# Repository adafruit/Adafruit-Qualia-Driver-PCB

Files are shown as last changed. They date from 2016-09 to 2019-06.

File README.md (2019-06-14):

## Adafruit Qualia Driver PCB

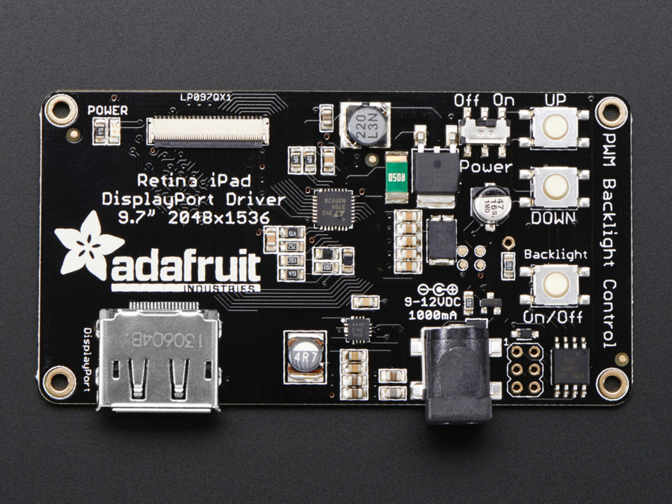
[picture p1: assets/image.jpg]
<a href="http://www.adafruit.com/products/1716"><br/>
Click here to purchase one from the Adafruit shop</a>

PCB files for the Adafruit Qualia Driver. Format is EagleCAD schematic and board layout
* https://www.adafruit.com/product/1716

### DESCRIPTION
The Qualia Retina driver board is a work of art (it was designed by resident engineer KTOWN). It's used in the Adafruit Qualia 9.7" DisplayPort Monitor Kit and we use the really awesome LT3754 as a 12-channel constant current driver with individual backlight string channel control. This gives the backlight perfect consistency over any usage or temperature range. A ATtiny85 handles the backlight dimming and soft on/off, so you can PWM the backlight over a range to get the look you want.

This driver is available for advanced users only! The Molex connector that is used to connect to the LG display is insanely delicate and breaks very very very easily if you are not very careful! If you order this driver board and break the connector, it may no longer work and we cannot repair it. If you break it you may have to buy another driver. We do not offer any returns, refunds or replacements! Do not purchase if you are not comfortable with this risk!

### License

Adafruit invests time and resources providing this open source design, please support Adafruit and open-source hardware by purchasing products from [Adafruit.com](https://www.adafruit.com)!

Designed by Adafruit Industries. 

Creative Commons Attribution, Share-Alike license, check license.txt for more information All text above must be included in any redistribution - see license.txt for more information.

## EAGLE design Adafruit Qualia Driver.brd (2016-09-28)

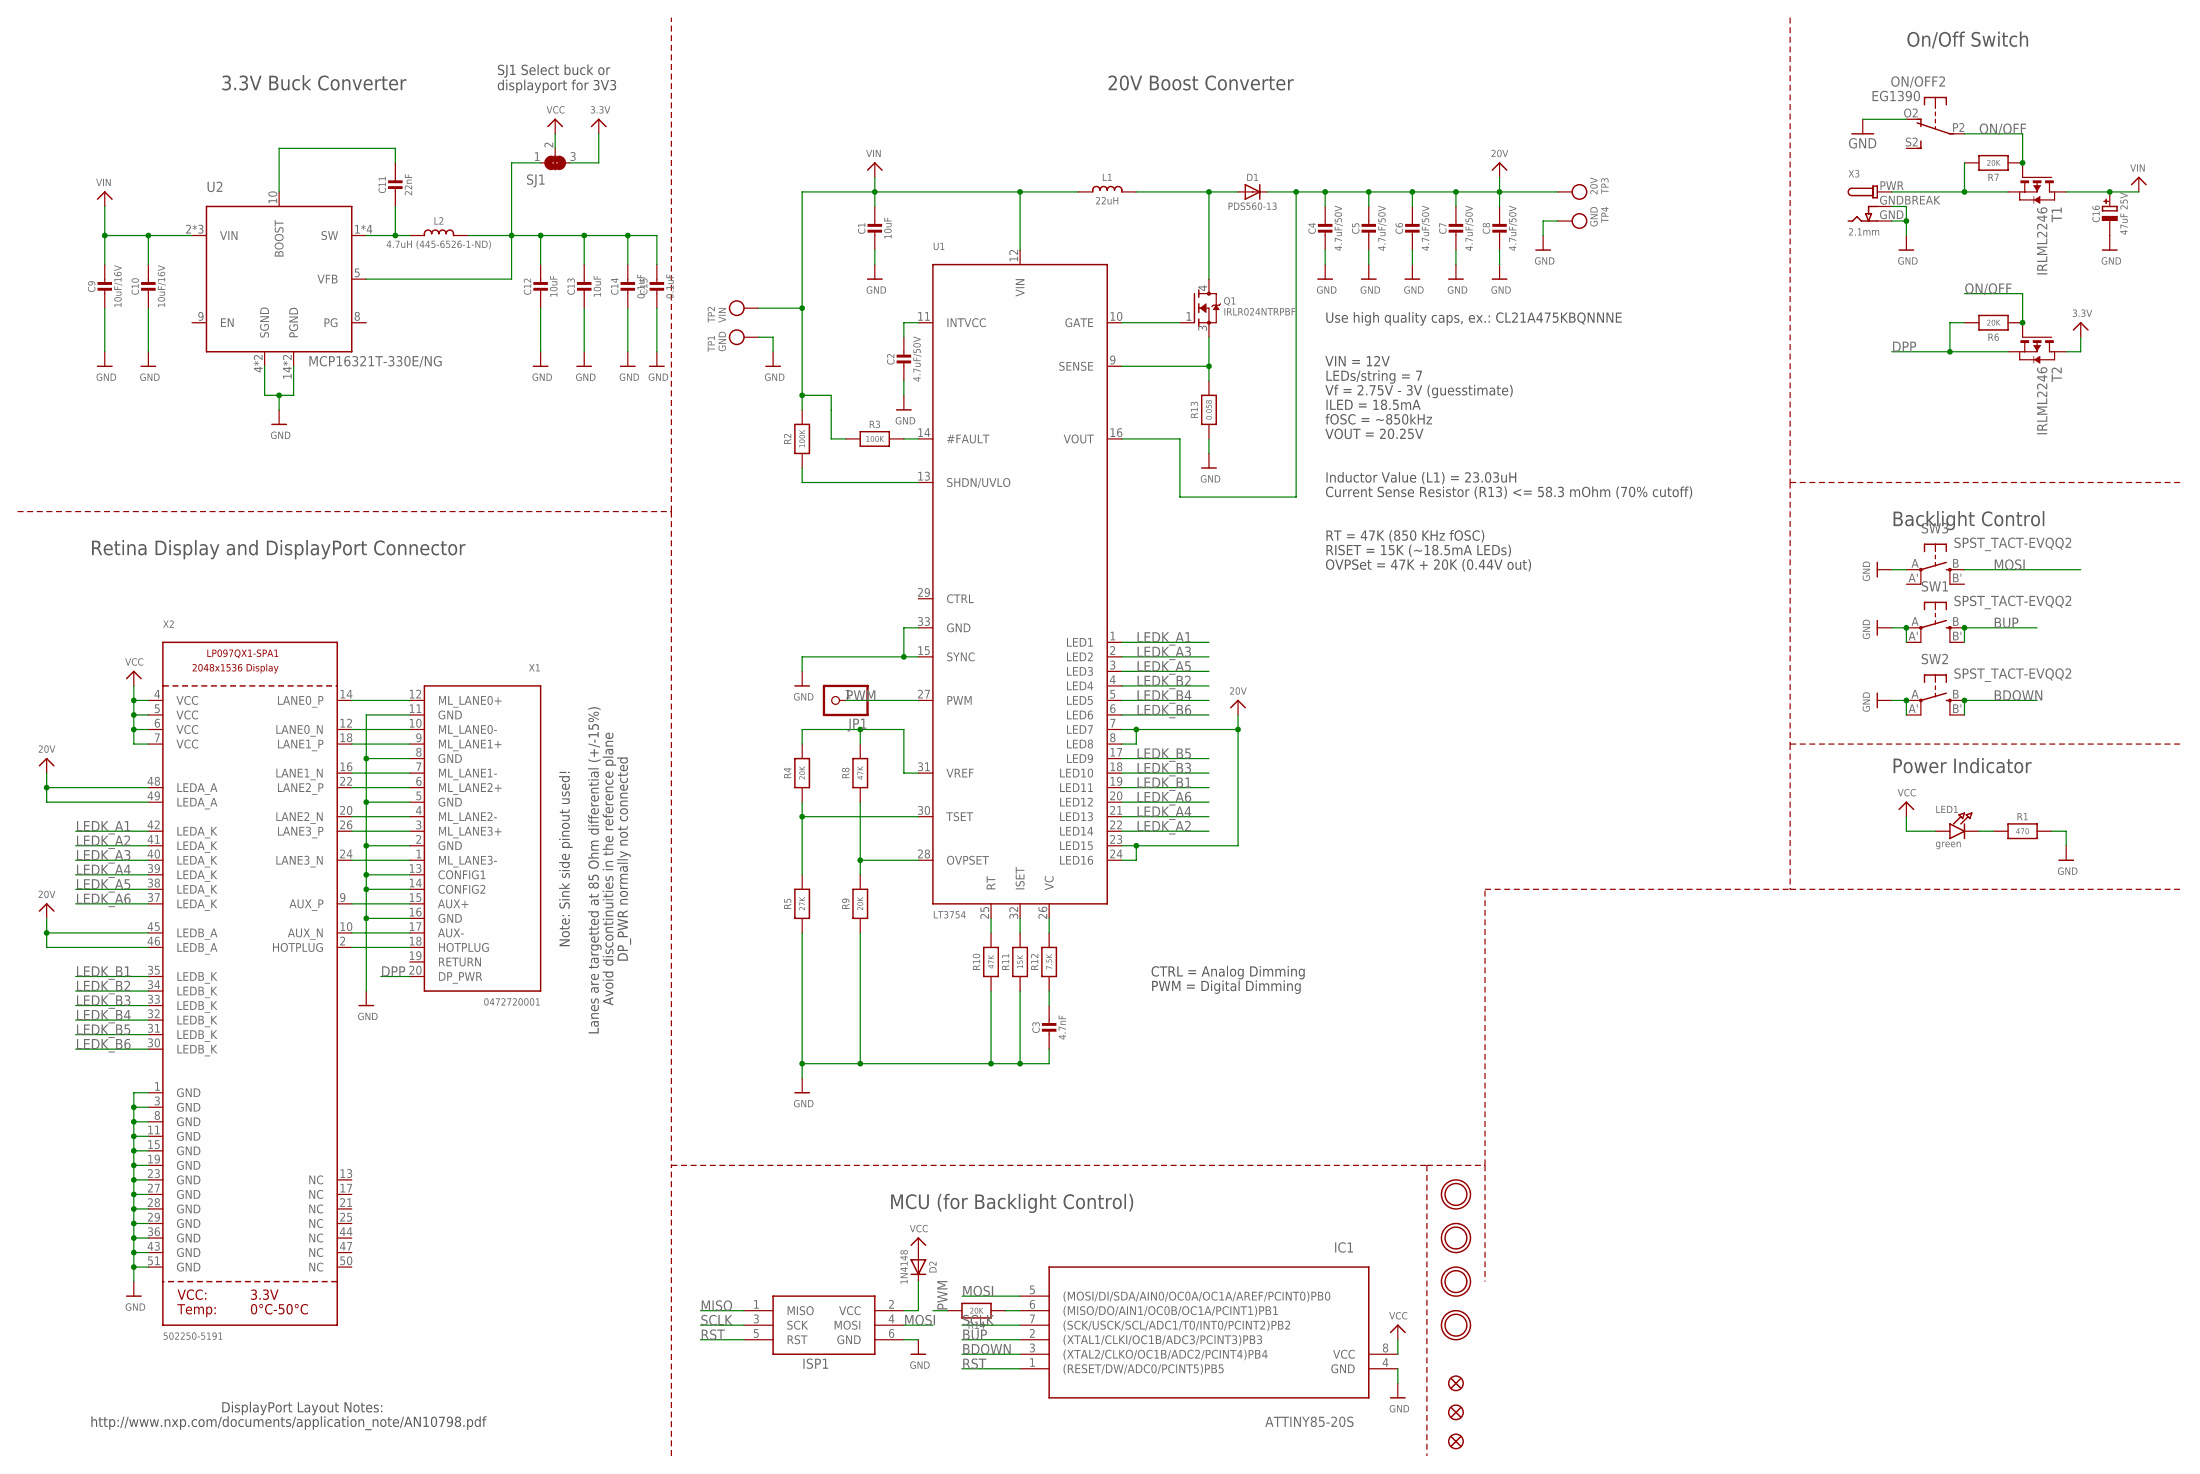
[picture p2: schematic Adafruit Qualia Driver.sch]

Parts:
C1, C12, C13: 10uF; _0805
C2, C4, C5, C6, C7, C8: 4.7uF/50V; _0805
C3: 4.7nF; _0805
C9, C10: 10uF/16V; _0805
C11: 22nF; _0805
C14, C15: 0.1uF; _0805
C16: 47uF 25V; PANASONIC_C
D1: PDS560-13; POWERDI-5
D2: 1N4148; SOD-323
FID1, FID2, FID3: FIDUCIAL""; FIDUCIAL_1MM
IC1: ATTINY85-20S; SOIC8
ISP1: AVRISP-6; AVRISP
JP1: PINHD-1X1CB; 1X01-CLEANBIG
L1: 22uH; INDUCTOR_6X6MM_SUMIDA_CDRH5D28
L2: 4.7uH (445-6526-1-ND); INDUCTOR_5X5MM_TDK_VLC5045
LED1: green; CHIPLED_0805
ON/OFF: EG1390
Q1: IRLR024NTRPBF; DPAK
R1: 470; _0805
R2, R3: 100K; _0805
R4, R9, R14: 20K; _0805
R5: 27K; _0805
R6, R7: 20K; _0805MP
R8, R10: 47K; _0805
R11: 15K; _0805
R12: 7.5K; _0805
R13: 0.058; 2512
SJ1: SOLDERJUMPER_2WAY; SOLDERJUMPER_2WAY_OPEN_NOPASTE
SW1, SW2, SW3: SPST_TACT-EVQQ2; EVQ-Q2
T1, T2: IRLML2246; SOT-23
TP1, TP4: GND; TESTPOINT_ROUND_1MM
TP2: VIN; TESTPOINT_ROUND_1MM
TP3: 20V; TESTPOINT_ROUND_1MM
U1: LT3754; QFN32_5MM
U2: MCP16321T-330E/NG; QFN16_3MM
U$11, U$32, U$33, U$34: MOUNTINGHOLE3.0THIN; MOUNTINGHOLE_3.0_PLATEDTHIN
X1: 0472720001; DISPLAYPORT_0472720001
X2: 502250-5191; FPC_51PIN_502250-5191_EXT
X3: 2.1mm; DCJACK_2MM_SMT

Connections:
3.3V: SJ1.3, T2.1 (D)
20V: C4.1, C5.1, C6.1, C7.1, C8.1, D1.C, TP3.P$1, U1.7 (LED7), U1.8 (LED8), U1.16 (VOUT), U1.23 (LED15), U1.24 (LED16), X2.45 (LEDB_A), X2.46 (LEDB_A), X2.48 (LEDA_A), X2.49 (LEDA_A)
AUX+: X1.15 (AUX+), X2.9 (AUX_P)
AUX-: X1.17 (AUX-), X2.10 (AUX_N)
BDOWN: IC1.3 ((XTAL2/CLKO/OC1B/ADC2/PCINT4)PB4), SW2.B (S), SW2.B' (S1)
BUP: IC1.2 ((XTAL1/CLKI/OC1B/ADC3/PCINT3)PB3), SW1.B (S), SW1.B' (S1)
DPP: R6.2, T2.2 (S), X1.20 (DP_PWR)
GND: C1.2, C2.2, C3.2, C4.2, C5.2, C6.2, C7.2, C8.2, C9.2, C10.2, C12.2, C13.2, C14.2, C15.2, C16.-, IC1.4 (GND), ISP1.6 (GND), ON/OFF.O2 (O), R1.2, R5.1, R9.1, R10.1, R11.1, R13.1, SW1.A, SW1.A' (P1), SW2.A, SW2.A' (P1), SW3.A, TP1.P$1, TP4.P$1, U1.15 (SYNC), U1.33 (GND), U2.4 (SGND), U2.14 (PGND), U2.15 (PGND), U2.THERMAL (SGND), X1.2 (GND), X1.5 (GND), X1.8 (GND), X1.11 (GND), X1.13 (CONFIG1), X1.14 (CONFIG2), X1.16 (GND), X2.1 (GND), X2.3 (GND), X2.8 (GND), X2.11 (GND), X2.15 (GND), X2.19 (GND), X2.23 (GND), X2.27 (GND), X2.28 (GND), X2.29 (GND), X2.36 (GND), X2.43 (GND), X2.51 (GND), X3.GND, X3.GNDBREAK
HOTPLUG: X1.18 (HOTPLUG), X2.2 (HOTPLUG)
LEDK_A1: U1.1 (LED1), X2.42 (LEDA_K)
LEDK_A2: U1.22 (LED14), X2.41 (LEDA_K)
LEDK_A3: U1.2 (LED2), X2.40 (LEDA_K)
LEDK_A4: U1.21 (LED13), X2.39 (LEDA_K)
LEDK_A5: U1.3 (LED3), X2.38 (LEDA_K)
LEDK_A6: U1.20 (LED12), X2.37 (LEDA_K)
LEDK_B1: U1.19 (LED11), X2.35 (LEDB_K)
LEDK_B2: U1.4 (LED4), X2.34 (LEDB_K)
LEDK_B3: U1.18 (LED10), X2.33 (LEDB_K)
LEDK_B4: U1.5 (LED5), X2.32 (LEDB_K)
LEDK_B5: U1.17 (LED9), X2.31 (LEDB_K)
LEDK_B6: U1.6 (LED6), X2.30 (LEDB_K)
MISO: IC1.6 ((MISO/DO/AIN1/OC0B/OC1A/PCINT1)PB1), ISP1.1 (MISO), R14.1
MOSI: IC1.5 ((MOSI/DI/SDA/AIN0/OC0A/OC1A/AREF/PCINT0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), ISP1.4 (MOSI), SW3.B (S)
unnamed: X1.12 (ML_LANE0+), X2.14 (LANE0_P)
unnamed: X1.10 (ML_LANE0-), X2.12 (LANE0_N)
unnamed: X1.9 (ML_LANE1+), X2.18 (LANE1_P)
unnamed: X1.7 (ML_LANE1-), X2.16 (LANE1_N)
unnamed: X1.6 (ML_LANE2+), X2.22 (LANE2_P)
unnamed: X1.4 (ML_LANE2-), X2.20 (LANE2_N)
unnamed: X1.3 (ML_LANE3+), X2.26 (LANE3_P)
unnamed: X1.1 (ML_LANE3-), X2.24 (LANE3_N)
unnamed: C2.1, U1.11 (INTVCC)
unnamed: R2.1, U1.13 (SHDN/UVLO)
unnamed: R3.2, U1.14 (#FAULT)
unnamed: R12.2, U1.26 (VC)
unnamed: C3.1, R12.1
unnamed: LED1.C, R1.1
unnamed: R4.1, R5.2, U1.30 (TSET)
unnamed: R4.2, R8.2, U1.31 (VREF)
unnamed: R7.2, T1.2 (S), X3.PWR
unnamed: R8.1, R9.2, U1.28 (OVPSET)
unnamed: R10.2, U1.25 (RT)
unnamed: D2.C, ISP1.2 (VCC)
unnamed: R11.2, U1.32 (ISET)
unnamed: Q1.3 (S), R13.2, U1.9 (SENSE)
unnamed: Q1.1 (G), U1.10 (GATE)
unnamed: D1.A1 (A), D1.A2 (A), L1.P$2 (2), Q1.4 (D)
unnamed: C12.1, C13.1, C14.1, C15.1, L2.P$2 (2), SJ1.1, U2.5 (VFB)
unnamed: C11.1, U2.10 (BOOST)
unnamed: C11.2, L2.P$1 (1), U2.1 (SW), U2.12 (SW), U2.13 (SW), U2.16 (SW)
ON/OFF: ON/OFF.P2, R6.1, R7.1, T1.3 (G), T2.3 (G)
PWM: JP1.1, R14.2, U1.27 (PWM)
RST: IC1.1 ((RESET/DW/ADC0/PCINT5)PB5), ISP1.5 (RST)
SCLK: IC1.7 ((SCK/USCK/SCL/ADC1/T0/INT0/PCINT2)PB2), ISP1.3 (SCK)
VCC: D2.A, IC1.8 (VCC), LED1.A, SJ1.2, X2.4 (VCC), X2.5 (VCC), X2.6 (VCC), X2.7 (VCC)
VIN: C1.1, C9.1, C10.1, C16.+, L1.P$1 (1), R2.2, R3.1, T1.1 (D), TP2.P$1, U1.12 (VIN), U2.2 (VIN), U2.3 (VIN), U2.11 (VIN)

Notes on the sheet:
Note: Sink side pinout used!
DP_PWR normally not connected
Lanes are targetted at 85 Ohm differential (+/-15%)
Avoid discontinuities in the reference plane
DisplayPort Layout Notes:
http://www.nxp.com/documents/application_note/AN10798.pdf
Use high quality caps, ex.: CL21A475KBQNNNE
Inductor Value (L1) = 23.03uH
VIN = 12V
LEDs/string = 7
Vf = 2.75V - 3V (guesstimate)
ILED = 18.5mA
VOUT = 20.25V
fOSC = ~850kHz
Current Sense Resistor (R13) <= 58.3 mOhm (70% cutoff)
RT = 47K (850 KHz fOSC)
RISET = 15K (~18.5mA LEDs)
OVPSet = 47K + 20K (0.44V out)
20V Boost Converter
MCU (for Backlight Control)
On/Off Switch
Retina Display and DisplayPort Connector
3.3V Buck Converter
CTRL = Analog Dimming
PWM = Digital Dimming
Backlight Control
Power Indicator
SJ1 Select buck or displayport for 3V3

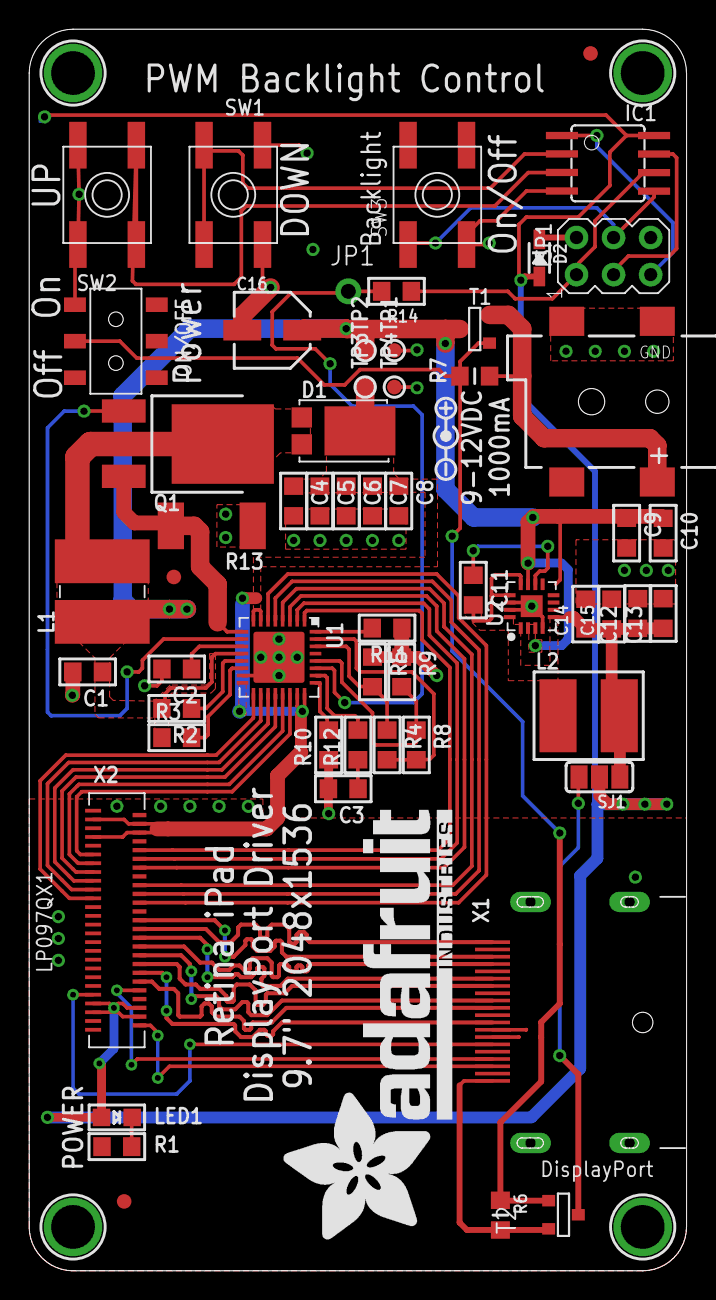
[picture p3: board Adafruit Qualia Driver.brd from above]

Board: 2 copper layers, 45.0 x 85.0 mm, 64 parts (0 on the bottom side), 56 nets.

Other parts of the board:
U$10: SYMBOL_POSITIVE_CENTER-M
U$39: ADAFRUIT_TEXT_30MM

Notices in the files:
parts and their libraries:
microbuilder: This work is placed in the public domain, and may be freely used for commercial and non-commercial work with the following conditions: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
